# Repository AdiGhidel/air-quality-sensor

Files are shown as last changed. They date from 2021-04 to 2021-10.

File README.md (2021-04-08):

# Air-quality-sensor
Air quality sensor - RPi + arduino

# Components
- 10W solar panel
- 4x18650 battery shield + charger
- Arduino nano
- 2x small buttons
- 1x big red button 🛑
- Raspberry Pi zero WH
- Enviro+ sensor
- PMS5003 fine particle sensor
- motor to turn on/off the big red button 🛑 (not servo as it has ~10mA idle consumption)

# How it works?
- Arduino will schedule a start&stop program for the RPI  
- The nano board implements deep sleep so the energy consumption will be pretty low  
- No servo chosen due to passive current consumption  
- No MOSFET used as a switch because it's not a 🛑Red Button  
- 2 Buttons used to adjust DC motor position for the 🛑Red Button 

# Raspberry setup 
Add the following line to crontab
```
crontab -e
###
@reboot sleep 15 && /usr/bin/python3 /home/pi/custom_script/sensor_reading.py&
###
```

Other boot.config changes
```
dtoverlay=dwc2
enable_uart=1
dtoverlay=adau7002-simple
start_x=0
dtoverlay=pi3-disable-bt # disables bluetooth
```

Disable hdmi:
- /etc/rc.local
```
/usr/bin/tvservice -o
```
Other power optimisations don't work
- usb is 'hardcoded'
- underclocking doesn't make much sense

The sensor will update the txt data for usage to a remote location (in my case a rpi with conky configured )

### Original sensor code
This didn't work for me as it loops continuosly (it can also change values on tap)  
[Pimoroni](https://github.com/pimoroni/enviroplus-python)

# Arduino setup
- uses 1/2 frequency (this means most stuff must be divided by 2 (seconds / baud rate))
- use deep sleep for efficient power mgmt
- 'disable' power led <==> break it with a screw-driver 
- idle power consumption -> 0.0027A (0.0095A with power led)
- uses EEPROM to keep the state of the switch even if power dies

# Schematics

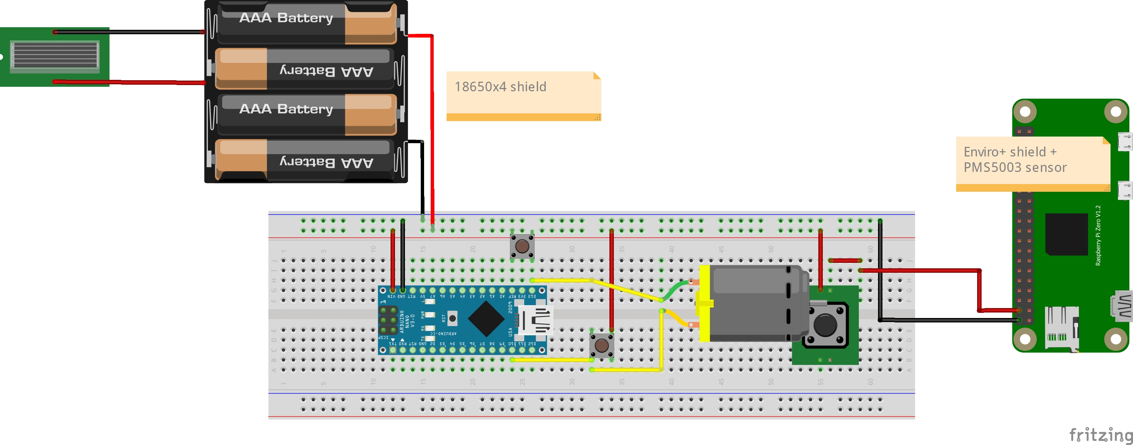
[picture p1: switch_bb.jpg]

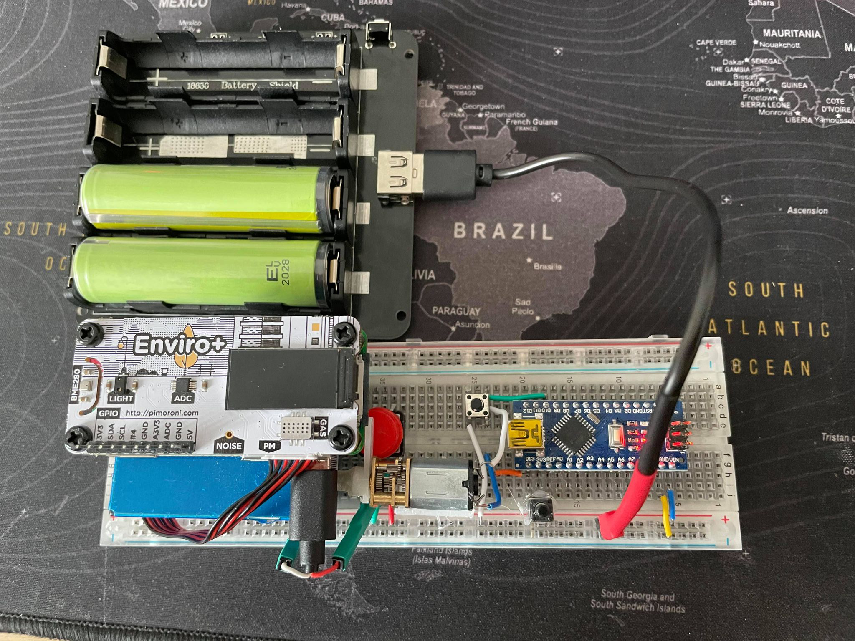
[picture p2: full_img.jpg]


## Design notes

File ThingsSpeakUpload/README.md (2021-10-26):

## Watcher script
- it detects changes to the to_upload folder and pushes the data to ThingsSpeaks
- the file is cleared afterward

### Service file location
/lib/systemd/system/sensor_upload.service

### Enabling the service
sudo systemctl enable sensor_upload.service

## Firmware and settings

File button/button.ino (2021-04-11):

#include "LowPower.h"
#include <EEPROM.h>

#define DEFAULT_SLEEP 8

#define L 2
#define R 13
#define CPU_FACTOR 2
int addr = 0;

#define DOWN 320
#define UP 280
void up(int ms) {
  EEPROM.write(addr, 1);
  digitalWrite(L, LOW);
  digitalWrite(R, HIGH);
  delay(ms);
  digitalWrite(L, LOW);
  digitalWrite(R, LOW);
  delay(100);
}

void down(int ms) {
  EEPROM.write(addr, 0);
  digitalWrite(L, HIGH);
  digitalWrite(R, LOW);
  delay(ms);
  digitalWrite(L, LOW);
  digitalWrite(R, LOW);
  delay(100);
}

void sleepFor(int seconds) {
  int counter = 0;
  while (counter < seconds) {
    counter += DEFAULT_SLEEP;
    LowPower.powerDown(SLEEP_8S, ADC_OFF, BOD_OFF);
  }
}
void sleepOne(int seconds) {
  int counter = 0;
  while (counter < seconds) {
    counter += 1;
    LowPower.powerDown(SLEEP_1S, ADC_OFF, BOD_OFF);
  }
}

void setup() {
  CLKPR = 0x80; // (1000 0000) enable change in clock frequency
  CLKPR = 0x01; // (0000 0001) use clock division factor 2 to reduce the frequency from 16 MHz to 8 MHz
  ADCSRA |= (1 << ADEN);
  pinMode(L, OUTPUT);
  pinMode(R, OUTPUT);
}

void loop() {
  int isUp = EEPROM.read(addr);
  if (isUp == 1) {
    down(DOWN / CPU_FACTOR);
  }
  sleepFor(210);
  Serial.println("going down");
  up(UP / CPU_FACTOR);
  sleepFor(1800);
}

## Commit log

2021-04-06 added sensor reading
2021-04-10 reverted board
2021-04-11 reworked logic for shutdown
    [button.ino]
